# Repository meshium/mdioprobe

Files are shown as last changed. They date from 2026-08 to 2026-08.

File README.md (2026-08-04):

# mdioprobe v2

An MDIO probe on a custom STM32G474CET6 board: it watches a Clause-22 bus
without touching it, and it can drive one.

- **Passive capture.** The analogue MDIO and MDC lines go through comparators
  with a DAC threshold; TIM3 counts 32 MDC edges from the start bit, an HRTIM
  latch turns that into chip-select for SPI2 in slave mode, and the CPU only
  decodes finished frames. No per-frame software setup, so a busy bus does
  not outrun it — 284350 consecutive frames from an 88E6321 PPU at 6.25 MHz
  MDC with no decode errors, ring overruns or DMA faults.
- **Active master.** Bit-banged Clause 22 up to 2.5 MHz through a tri-state
  buffer powered from a programmable supply, so MDC comes out at the target's
  own logic level. Reads go back through the same comparator front end, which
  is why no receive-side translator is needed.
- **Level-agnostic.** The target's rail is measured, not assumed: 1.8, 2.5 and
  3.3 V buses are detected and every threshold derives from that one number.
  Until a rail is known, capture and the master both refuse to run.
- **Chip identification.** Registers 2 and 3 are looked up in a table
  extracted from the Linux kernel sources — 302 PHYs and 120 DSA switches,
  frozen into the firmware, so it works on a blank volume.

The command interface is a MicroPython CLI over USB CDC ACM, with history,
TAB completion, output redirection to files and a QSPI NOR volume for scripts
and logs.

```
mdio /flash> probe
phy 05: 4f51e91a  YT8531S Gigabit Ethernet
1 device(s) answered with an identifier

mdio /flash> read 5 2-3
reg 0x02 = 0x4f51
reg 0x03 = 0xe91a
```

## Building

Zephyr, with the board definition in-tree. The MicroPython submodule is
needed first:

```
git submodule update --init --recursive
./build.sh              # build
./build.sh flash        # build and flash over SWD
```

`build.sh` is the only supported entry point. It sources the Zephyr
environment, pins a toolchain and calls `west`, and it takes nothing on trust
from the machine it runs on:

| | |
| :-- | :-- |
| `ZEPHYR_BASE` | the Zephyr tree; defaults to `~/zephyrproject/zephyr` |
| `MDIOPROBE_SDK` | which SDK; defaults to the newest `~/zephyr-sdk-*` |
| `MDIOPROBE_VENV` | virtualenv to activate, and only when `west` is not already on `PATH` |

If your Zephyr environment is already active, the script uses it and changes
nothing. If a path is missing it says which one, rather than failing deep
inside CMake.

## Console

There is no VCP on the board. The log and the CLI share **USB CDC ACM**
(`/dev/tty.usbmodem*`); SWD on PA13/PA14/PB3 is for debugging. `tools/con.py`
is the bench driver for the console.

`help` lists the commands and `help <command>` explains one. USB is either the
console or a mass-storage device, never both at once: `msd` hands the volume
to the host and takes the console away until the probe is unplugged.

## Layout

```
src/            firmware; the public surface is include/mdioprobe_api.h alone
src/python/     the CLI, frozen into the image
boards/         the board definition (HWMv2)
hardware/       KiCad project: schematic, PCB, gerbers
docs/CAPTURE.md   how a frame is captured, end to end
docs/HARDWARE.md  pinout, connector, and what the schematic actually does
tools/con.py    console driver for the bench
tools/upload.py put files on the volume without unplugging
```

Zephyr APIs are used for ADC, GPIO, flash, UART, I2C and USB; the comparators,
TIM3, HRTIM, the SPI2 slave ring and the bit-bang master are driven through
STM32Cube LL and direct register writes, because Zephyr does not expose the
COMP-to-timer crossbars and its STM32 SPI slave driver races its own DMA.

## Status

Pre-release. Bring-up is complete and verified on hardware, including capture
against a real external master. Not yet exercised: the `uart` and `i2c`
connector personalities, and the short-circuit latch on the programmable
supply.

## Licence

Two objects, licensed separately, which is the usual practice for open
hardware and the only one that reads sensibly — a software licence does not
define what "object form" or "linking" mean for a printed circuit board.

- **Firmware and everything else: Apache-2.0**, text in `LICENSE`. The image
  is a static link, so a binary release carries Zephyr, MicroPython, the
  STM32Cube LL drivers, FatFs and picolibc with it; `NOTICE` lists each
  component and its terms and belongs with the binary, not only with the
  source.
- **The board, under `hardware/`: CERN-OHL-P-2.0**, text in
  `hardware/LICENSE`. Permissive, to match the firmware, and written for
  hardware — unlike a Creative Commons licence it grants patent rights, which
  for a circuit board is the part that matters.

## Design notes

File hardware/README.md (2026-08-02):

# mdioprobe v2 — board

SPDX-License-Identifier: CERN-OHL-P-2.0

KiCad 8 project for the probe: schematic, PCB, the footprints that are not in
the standard libraries, and a gerber set.

```
mdioprobe.kicad_sch     schematic
mdioprobe.kicad_pcb     board
mdioprobe.netlist       netlist
footprints.pretty/      footprints not in the KiCad libraries
gbr/                    gerbers and drill files
```

The KiCad footprint cache (`fp-info-cache`) and per-user project settings
(`*.kicad_prl`) are not tracked: KiCad rebuilds the first from the libraries
on demand, and the second is local to whoever opened the project.

## Licence

Everything in this directory is under the **CERN Open Hardware Licence
Version 2 — Permissive** (`LICENSE` here, SPDX `CERN-OHL-P-2.0`).

**The firmware is not.** The rest of the repository is Apache-2.0, with its
own `LICENSE` and `NOTICE` at the top level. Hardware and software are
different objects in law and are licensed separately, which is the usual
practice and the only one that makes sense: a software licence has nothing to
say about what "object form" or "linking" mean for a printed circuit board.

CERN-OHL-P rather than a Creative Commons licence, for two reasons. It is
written for hardware — it defines Source as the design files, Product as the
thing you build from them, and it covers making and having made, none of
which a licence written for creative works addresses. And it grants patent
rights (§6.1), which CC 4.0 explicitly does not (§2(b)(2): "Patent and
trademark rights are not licensed"). For hardware that gap is in exactly the
place the risk lives — the design files would be yours to copy while the
right to build the thing was not.

Permissive rather than the reciprocal variant (CERN-OHL-S): it matches the
firmware's Apache-2.0, and the point of publishing this board is that people
can use it, including inside something they do not open.

There is no warranty and no liability, per sections 5 and 8 of the licence.
This is a bench instrument, not a certified one.

## What it is

STM32G474CET6 in LQFP48. Comparators with a DAC threshold on the MDIO and MDC
inputs, a tri-state buffer on the MDC output powered from a programmable
soft-LDO so the probe drives at the target's own logic level, QSPI NOR for
storage, and USB.

`docs/HARDWARE.md` in the repository root is the pinout, the connector, and
the parts of the schematic worth knowing about before changing anything —
including what the next board revision needs.

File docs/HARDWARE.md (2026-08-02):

# MDIO Probe v2 — hardware map

MCU: **STM32G474CET6**, LQFP48, 512 KB flash / 128 KB RAM, 170 MHz.
No crystal: HSI16 → PLL (M=4, N=85, R=2) = 170 MHz; USB FS on HSI48 + CRS.

**The missing crystal is not only a USB concern.** HSI16 is the only
reference behind anything that measures time. Measured on this unit:
`kernel uptime` against the host clock over 120 s runs **+660 ppm** fast,
and the MDC frequency measurement reads low by the same amount (−721 ppm
against a scope-confirmed 6.250 MHz). The datasheet allows ±1%. Framing
does not care — TIM3 counts real edges — but no absolute time figure from
this board is good beyond about three significant digits.

## 1. Full pin map

| Pin | Signal | Function in firmware |
| :-- | :-- | :-- |
| PA0 | SPI2_SCK source | COMP1_OUT (AF8), MDC digital → **PCB trace to PB13** |
| PA1 | MDC sense | COMP1_INP (Analog) — sniffed clock |
| PA2 | QSPI_NSS | QUADSPI1_BK1_NCS |
| PA3 | QSPI_SCK | QUADSPI1_CLK |
| PA4 | VREG_CTL | DAC1_OUT1 (buffered) → P-MOSFET gate |
| PA5 | — | unused |
| PA6 | QSPI_D3 | QUADSPI1_BK1_IO3 |
| PA7 | QSPI_D2 | QUADSPI1_BK1_IO2 |
| PA8 | SPI2_MOSI source | COMP7_OUT (AF8), MDIO digital → **PCB trace to PB15** |
| PA9 | LED_G | GPIO, active low |
| PA10 | SPI2_NSS source | HRTIM1_CHB1 (AF13), NSS latch → **PCB trace to PB12** |
| PA11 / PA12 | USB_N / USB_P | USB FS device (CDC ACM console) |
| PA13 / PA14 | JTMS / JTCK | SWD |
| PA15 | JTDI | reserved |
| PB0 | QSPI_D1 | QUADSPI1_BK1_IO1 |
| PB1 | QSPI_D0 | QUADSPI1_BK1_IO0 |
| PB2 | VREG | ADC2_IN12 — regulated translator supply sense |
| PB3 | JTDO | reserved |
| PB4 | — | unused |
| PB5 | PHY_RST | GPIO open-drain, no pull, active low |
| PB6 | MDC_EN | GPIO **open-drain**, active low — buffer enable; 4.7 kΩ pull-up to VREG |
| PB7 | MDC_OUT | GPIO push-pull — bitbang MDC into the buffer |
| PB8 | MDIO out / USART3_RX / I2C1_SCL | direct to connector; OD no pull (MDIO TX) / Analog (RX, or parked) |
| PB9 | USART3_TX / I2C1_SDA | direct to connector, 3.3 V; parked (Analog) in MDIO mode |
| PB10 | — | unused |
| PB11 | LED_R | GPIO, active low |
| PB12 | SPI2_NSS | AF5 — chip select from PA10 |
| PB13 | SPI2_SCK | AF5 — clock capture from PA0 |
| PB14 | MDIO sense | ADC1_IN5 + COMP7_INP (Analog) — sniffed bus **and** master read-back |
| PB15 | SPI2_MOSI | AF5 — data capture from PA8 |

Internal-only, no pins: **DAC3_CH1** → COMP1_INM (MDC threshold),
**DAC4_CH1** → COMP7_INM (MDIO threshold).

## 2. Target connector

| Line | Driven by | Notes |
| :-- | :-- | :-- |
| MDC (MDIO mode) | PB7 → SN74LV1T125DBV buffer | enabled by MDC_EN (PB6, active low, open-drain); buffer VCC = VREG, so MDC swings at the target's level — measured 1800 → 1816…1840 mV, 2500 → 2543…2566, 3300 → 3176…3200; output also loops back to PA1/COMP1 |
| USART3_TX / I2C1_SDA | PB9, **direct** | bypasses the buffer — fixed 3.3 V |
| MDIO | PB8 out + PB14 in | **two MCU pins, one connector line**: PB8 drives (OD), PB14 senses via COMP7 |
| USART3_RX / I2C1_SCL | PB8, direct | same pin as the MDIO driver, different personality |
| PHY_RST | PB5 | open-drain, no pull — pull-up must come from the target |
| GND | — | |

Exactly one personality is live at a time, and the two never overlap on the
shared connector line:

- **MDIO mode** — PB7 clocks the buffer, PB8 drives data, PB14 reads it back.
  PB9 is parked (Analog) and both serial peripherals sit in their "sleep"
  pinctrl state, so nothing loads the bus the analog front end measures. The
  MDIO drive pin is Analog while receiving, open-drain (no pull) while
  transmitting.
- **UART / I2C mode** — the buffer is **off** (otherwise it would fight PB9
  on the same connector line), PB8/PB9 drive the connector directly at a
  fixed 3.3 V. No level translation on this hardware revision: the
  programmable supply feeds only the MDC buffer. I2C is master-only, and SDA
  stays bidirectional end to end because it never crosses the buffer.

## 3. Programmable translator supply (vreg)

An external P-MOSFET pass element driven by DAC1_CH1 (PA4), Vout sensed by
ADC2_IN12 (PB2), a 20 kHz TIM6 ISR running the PI loop, and an ADC analog
watchdog for short-circuit cutoff.

The control tick is a **zero-latency IRQ**. It has to be: the bitbang
master holds `irq_lock()` for a whole frame, and an ordinary interrupt would
leave the loop blind for all of it. Measured on a back-to-back burst when a
frame was ~430 µs — 8-9 missed ticks — that cost 2711 mV of swing on an
1800 mV target, against 43 mV with the tick unmaskable.

Raising MDC to 1500 kHz shortened the frame to ~44 µs, so the exposure is now
under one tick and the burst test would no longer show the difference. The
zero-latency tick stays: `clock` can be wound back down to 10 kHz, where a
frame is 6.4 ms and the old numbers apply with interest.

**The board is missing a bleeder resistor from VREG to GND** (~1 kΩ). The
pass element can only source current, so without a discharge path an
overshoot decays through ~40 µA of leakage, which shows up as a sawtooth.
It is currently clipped on at the bench — put it on the next revision.

```
      Vin 3.3V
        ├───[ R_pu 100k-1M ]───┐
    ┌───┴────┐ S               │
    │P-MOSFET│ G ◄─────────────┴──── PA4  (DAC1_OUT1, buffered)
    └───┬────┘
        │ D ──► Vout (1.8-3.3 V) ──► MDC buffer / level translator supply
      [ Cout ]  └───────────────────  PB2  (ADC2_IN12)
        │
       GND
```

**Range: 1800–3000 mV regulated, above that pass-through.** This is a
property of the topology, not a setting: a series pass element needs some
voltage across it to be controllable, and Vin is only 3.3 V. At a 3000 mV
target the gate still moves the output by 20 mV per DAC code; at 3300 it
bottoms out at `dac_code = 0` and there is no regulation left.

So a request above 3000 mV puts the node into `PASSTHRU`: gate fully on,
output = the board's 3.3 V minus a fraction of a millivolt across Rds(on) at
our few milliamps. For a target with 3.3 V logic that is exactly right, and
tighter than the loop could manage anyway — 8 mV p-p under continuous
generation, against 63 mV at a regulated 3000.

Two things about `PASSTHRU` worth remembering:

- **Measuring the output stops meaning anything.** VDDA = VREF+ = the same
  3.3 V as Vin, so the ADC measures the rail against itself and always reads
  near full scale. Do not take an absolute value from it.
- **Short-circuit protection still works but loses discrimination.** The
  FAULT condition is "gate saturated AND the analog watchdog active for 100
  ticks". Gate saturation used to mean the loop had given everything it had;
  here it is true by construction, so only the 5 ms debounce remains. The
  threshold itself stays meaningful — a short pulls Vout down relative to
  VDDA.

There is nothing between 3000 and 3300: a request for 3100 would silently
deliver 3.29 V, so it collapses into pass-through and the driver says so.

Control interface: `mdioprobe_vreg_set()` / `_off()` / `_get()` in
`include/mdioprobe_api.h`; the PI gains and the short-circuit margin are
tunable through the private `src/mdioprobe_vreg.h`.

## 4. QSPI NOR

Winbond **W25Q80DVSNIG**, 8 Mbit, bank 1, memory-mapped window at 0x90000000.
Driven by Zephyr's `st,stm32-qspi-nor` driver; partitions `capture` (768 KB)
and `qspi-storage` (256 KB).

The `quadspi` DT node itself comes from Zephyr's G4 SoC dtsi — only pinctrl,
the flash child and partitions live in the board DTS.

**`writeoc = "PP_1_1_4"` is mandatory in the DTS.** The driver's default page
program opcode is 0x38 (PP_1_4_4), which this part does not implement — and
it does not fail: the write is accepted, nothing is programmed, and the
error only surfaces as a verification mismatch later. SFDP carries no
quad-program information, so nothing detects this automatically.

## 5. Hardware facts worth restating (confirmed against the schematic)

1. **Serial personalities are 3.3 V only.** PB8/PB9 reach the connector
   directly; the tri-state buffer and the programmable supply are on the MDC
   path alone. Only an I2C **master** and a UART are supported on this
   revision.
2. **The buffer is exclusive to MDC.** In UART/I2C mode `mdioprobe_serial.c`
   de-asserts MDC_EN; in MDIO mode PB9 is parked. The two sources never
   drive the connector line at once.
3. **Generated MDC loops back to PA1/COMP1** from the buffer output, so the
   frequency measurement and the threshold autocal have a clock source even
   with no external master. That self-trigger only fires when the line is
   genuinely idle — driving MDC into a bus that already has a master is a
   collision, and it also corrupts the measurement, because our ~130 kHz
   bitbang becomes the majority of the sample and the real megahertz clock
   is rejected as outliers.
4. **VDDA = VREF+ = 3.3 V**, which is what the DAC threshold maths in
   `mdioprobe_adc_dac.c` assumes.
5. **LED colours are PA9 = green, PB11 = red** — the reverse of the initial
   pinout notes, confirmed by watching an LED-only image on real hardware.
6. **MDC_EN must be driven open-drain.** The line has a 4.7 kΩ pull-up to
   VREG — the buffer's own supply. Push-pull HIGH feeds the 3.3 V domain
   into the VREG rail through that resistor; since the rail's only load is
   the buffer's quiescent current, it floats up to ~3.26 V regardless of
   the pass MOSFET, and the vreg loop saturates its gate fully shut trying
   to correct an output it does not actually control. Observed as
   `target=2989 measured=3257 dac_code=4095`.
7. **The MDC_EN release edge is measured and clean.** On a scope, OE rises
   **1…2.5 µs after the falling edge of the last MDC pulse**, with a steep
   edge — the 4.7 kΩ pull-up does not smear it, so the OE node capacitance
   is what the estimate assumed (τ ≈ 4.7 kΩ × 10-15 pF ≈ 50-70 ns). The
   1…2.5 µs is firmware, not RC: `irq_unlock()` sits between the last
   `mdc_set(0)` and the buffer being released, and the lock had been held
   for the whole frame, so every deferred interrupt flushes there. Harmless
   — MDC is parked low before the unlock and the bus rests low anyway.
   Releasing the buffer is deliberately kept **outside** the lock, so the
   load step does not land on a blinded vreg loop.
8. **The MDC buffer is a TI SN74LV1T125DBV** — a single-bit 3-state buffer
   and one-way level translator, VCC = VREG. Datasheet facts that matter:
   - **VCC range 1.8–5.5 V**, so VREG's whole 1.8–3.3 V span is in spec;
   - **inputs tolerate 5 V regardless of VCC** — driving PB7 push-pull at
     3.3 V into a buffer powered from 1.8 V is a designed-for case, not an
     overvoltage. No clamp-diode current, nothing to fix;
   - **OE is active low**, matching MDC_EN;
   - *reduced* input thresholds (at VCC 3.3 V it is specced for 1.8 V
     inputs, at 1.8 V for 1.2 V ones), so our 3.3 V swing is read reliably.

   Net effect: the input side lives in the MCU's 3.3 V domain, the output
   side swings at the target's level. Being a single buffer, it also
   confirms that only MDC crosses it — PB8/PB9 reach the connector direct.

9. **PB8 is also BOOT0 — every board needs `nSWBOOT0 = 0`.** RM0440 §2.6.1,
   Table 5: out of the factory `nSWBOOT0 = 1` (BOOT0 comes from the PB8 pin)
   and `nBOOT1 = 1`, so a high level on PB8 at reset release boots System
   memory — the ROM bootloader — instead of our firmware. PB8 carries MDIO
   straight to the connector, and any live target pulls that line up, so a
   factory-configured board **does not start at all once the target is
   connected**.

   One-time per board, over SWD:

   ```
   STM32_Programmer_CLI -c port=SWD mode=UR -ob nSWBOOT0=0
   ```

   BOOT0 then comes from the `nBOOT0` option bit, which is already 1 → main
   flash regardless of the pin. `west flash` does not set this — it is a
   per-device setting, not part of the image. A pull-down on PB8 is **not**
   an alternative: it would divide against the target's MDIO pull-up.

10. **MDIO needs a pull-up, and this board does not always have one.** The
    line is open-drain in both directions: PB8 only ever pulls low, so every
    '1' — including every bit the target sends back — is a resistor charging
    the line. Nothing on the MDC path helps here; the buffer is one-way and
    on the other wire entirely.

    Two v2 boards exist, one with an external pull-up fitted on MDIO and one
    without, and the difference is not cosmetic: on the board without it a
    Marvell 88E6321 returned nothing but `0xffff` to every read, while the
    same firmware on the pulled-up board read it correctly. The switch's own
    internal weak pull-ups are **not** sufficient. Note that this contradicts
    the assumption in item 9 that "any live target pulls that line up" — a
    target may well not, which is also why that board still booted.

    The failure looks exactly like clocking MDC too fast, and it is worth
    knowing that it is not: an all-`0xffff` read is a floating line far more
    often than it is a slow one, and slowing `clock` will not rescue it.
    Fit the pull-up. Every board should carry one — 1.5–4.7 kΩ to the
    target's rail (i.e. to VREG, not to 3.3 V) — and that belongs in the
    next revision alongside the vreg bleeder.

    Decided for that revision: **one resistor behind a switch**, not a
    permanent one. Permanent to VREG would break the rail measurement in
    both directions — with VREG off the resistor is a path to a dead node,
    with VREG on the probe would be measuring its own rail and could never
    see the target leave. The switch stays open until the rail is known,
    which keeps today's automatic detection exactly as it is and adds the
    case it cannot handle.

    What the firmware owes in return: while the switch is closed the probe
    can no longer tell the rail or whether a target is attached — no passive
    observer can distinguish 1.8 V from 3.3 V on a wire it is holding up
    itself — so that state has to be visible in `diag` and on the LED rather
    than discovered.

11. **How fast MDC can actually go, measured three ways.** These are three
    different limits and only the first belongs to the probe:

    | Limit | Rate | What sets it |
    | :-- | :-- | :-- |
    | Bit loop | ~4.0 MHz | GPIO writes, the shift-and-mask and the cycle-counter spin, at 170 MHz and `-Os` |
    | Clause 22 | 2.5 MHz | IEEE 802.3 §22.2.2.11, the specified MDC maximum |
    | This bench | ~1.8 MHz | an 88E6321 over a short lead stops answering above it |

    The bench figure is a sweep, not an estimate: 1205, 1317, 1556 and
    1762 kHz delivered gave 10/10 correct switch-ID reads each, while
    2096 kHz and above gave 0/10. Nothing in between was tried, so the edge
    is somewhere in that gap. The firmware default is 1500 kHz, which leaves
    margin under it; 300 indirect reads at 1451 kHz delivered ran with no
    mismatches and no errors.

    Since MDIO is open-drain, the third row is a property of the pull-up and
    the wiring rather than of either device, so expect it to move with the
    lead and the resistor. A stronger pull-up is the thing to try if a target
    needs to run faster.

12. **The MDC buffer stays enabled between frames, and MDC is driven while
    it does.** The firmware releases it 20 ms after the last frame rather
    than after each one, so a series of transactions enables it once. While
    it is up, PB7 drives MDC through the buffer and holds it low at idle —
    which means that for those 20 ms the probe owns the clock line and
    another master on the same wire cannot use it.

    Observable without a scope: with the buffer released, the target's
    pull-up wins and `diag` reports `comp MDC: 200/200 high`; immediately
    after a frame it reads lower, because part of the sampling window caught
    the line held low.

    What this buys is the settle. Enabling the buffer is a load step on the
    VREG rail, so it is followed by a 1 ms wait whenever the supply is
    regulating — paying that once per series instead of once per transaction
    is the whole point. In pass-through there is no loop to protect and the
    wait is skipped entirely (measured: a 200-transaction burst leaves the
    rail inside its idle window either way, and the transaction drops from
    1081 µs to 84).

13. **The bench target's "PPU traffic" is the switch polling two external
    PHYs, and one scratch bit decides whether that bus exists.** This was
    used blind through the whole bring-up — `mv scratch modify clear 6 0x63
    0x80` made frames appear and setting the bit again silenced them — so
    the mechanism is worth writing down.

    On the 88E6321, `scratch[0x63]` bit 7 is `NormalSMI` (Functional
    Specification Table 208, p. 334). With P5_MODE not 0x1 or 0x2, the
    P5_COL and P5_CRS pins become MDIO_PHY and MDC_PHY *if the NO_CPU strap
    was one at reset*; clearing the bit inverts the sense of that strap.
    Nothing else routes an external MDIO bus off this part.

    On this bench NO_CPU is 0 (`scratch[0x71] = 0x83`), so the pins carry
    the external bus only with NormalSMI **cleared**. Measured both ways:
    with it set, PHY addresses 5 and 6 read `0xffff`; with it cleared they
    answer (BMSR 0x7949, ID 0x4f51/0xe91a). External PHYs sit on ports 5
    and 6 of this board, so those are the two the PPU polls, and that is
    the traffic the capture chain was verified against.

    Address map, since the same window reaches all of them (spec §9.3):
    internal PHYs of ports 3 and 4 at SMI addresses 3 and 4, internal
    SERDES of ports 0 and 1 at 0x0C and 0x0D, external PHYs at the address
    matching their port number. `mv extbus` and `mv id` print all of this.

    **Two ways to an external PHY, and they are independent.** The SMI PHY
    window reads the PHY's registers directly. The PPU is the other one: it
    polls the PHY whose SMI address matches the port number and publishes
    link/speed/duplex into that port's status register for the MAC. Only
    the second needs the port's `PHYDetect` bit (Port offset 0x00 bit 12),
    and **the PPU's own detection does not always set it** — measured here,
    ports 5 and 6 stayed `no PHY detected` with the bus routed and both
    PHYs answering, through a soft reset as well.

    PHYDetect is the one writable bit in that register and the spec says
    the poll routine follows it, so setting it by hand is the fix
    (`mv port <sw> <ports> detect on`). Measured: port 5 went from
    `0x0e07` — link up, 1000 Mbps, no PHY detected — to `0x1007`, link
    down with the PHY detected, i.e. the PPU replaced a status that had
    not come from a PHY at all with the real one. A Global1 software reset
    re-runs PPU init and rewrites the register, so the setting does not
    survive one.

    One more thing that only the spec says: the switch's SMI PHY window
    (Global2 0x18/0x19) works **only while the PPU is enabled** — with it
    off, SMIBusy self-clears and every read returns `0xffff`. The enable is
    Global1 0x04 bit 14, which the register table calls "Reserved, must be
    set to 1" while the footnote under the SMI PHY register names it. Note
    it is *not* PPUState in Global1 0x00 bit 15: measured with the PPU
    disabled, status went 0xc800 → 0x8800, so bit 15 stayed at "polling".

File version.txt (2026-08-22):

# Release version of the firmware.
#
# MAJOR and MINOR are bumped deliberately, by hand — they say what release
# this is meant to be. PATCH is counted rather than chosen: a commit hook
# increments it and stages the result, so every commit carries its own. The
# build itself never writes here.
MAJOR=0
MINOR=1
PATCH=14

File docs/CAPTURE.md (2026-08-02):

# MDIO Capture — End-to-End Flow

This document describes the complete data path for capturing a single
Clause-22 MDIO frame: from the analog wire on the target board, through
the on-chip analog/timer/SPI front end, to a 32-bit decoded frame in
RAM. It is the reference for understanding *why* every peripheral is
configured the way it is in `src/mdioprobe_*.c`.

---

## 1. Why hardware-only capture

Clause-22 MDIO at 2.5 MHz means an MDC edge every 200 ns; live PPU
traffic from the MV88E6321 runs faster still (~6.27 MHz). A
software-ISR-per-bit approach is out of the question on a 170 MHz
Cortex-M4. Even DMA-from-GPIO is awkward because the start of a frame
is not self-clocked — we have to detect the preamble→ST=0 transition to
lock onto the 32-bit data field.

We solve this by chaining on-chip peripherals so the CPU is involved
only in **decoding the captured 32-bit word**, never in clocking,
edge-detection, or framing:

```
analog → comparators → TIM3 counter + HRTIM latch (NSS) → SPI2 slave + DMA → RAM
```

The CPU sleeps in `k_sleep(2 ms)` polling a ring-buffer index while the
hardware does the rest.

---

## 2. Structural block diagram

```
   ┌─────────────────────────── mdioprobe_v2 board ────────────────────────────┐
   │                                                                           │
   │  Target ── MDC ──► PA1 ──►┌ COMP1 ┐                                       │
   │                           │ + -   │ comp1_out ─► PA0 (AF8) ─[trace]► PB13 │
   │            DAC3_CH1 ─────►┘       │            (digital MDC)    SPI2 SCK  │
   │            (MDC threshold, internal-only)                                 │
   │                                                                           │
   │  Target ── MDIO ─► PB14 ──►┌ COMP7 ┐                                      │
   │            (ADC1_IN5)      │ + -   │ comp7_out ─► PA8 (AF8) ─[trace]► PB15│
   │            DAC4_CH1 ──────►┘       │            (digital MDIO)  SPI2 MOSI │
   │            (MDIO threshold, internal-only)                                │
   │                                                                           │
   │  comp1_out ─internal─► TIM3_ETR  (external clock, MDC edges)              │
   │  comp7_out ─internal─► TIM3_TI1  (trigger)  and  HRTIM EEV5               │
   │                                                                           │
   │  ┌──────────── TIM3 (one-pulse, ARR=32) ─────────────┐                    │
   │  │  trigger (comp7_out ↓ = ST) starts the counter    │                    │
   │  │  ETR (comp1_out ↑ = MDC) clocks it 0→32           │                    │
   │  │  OPM stops at 32; MMS=Enable → TRGO = CNT_EN      │                    │
   │  └──────────────────────┬────────────────────────────┘                    │
   │                         │ tim3_trgo (CNT_EN) ─internal─► HRTIM EEV3       │
   │  ┌──────────── HRTIM1 Timer B — NSS SR latch ────────┐                    │
   │  │  SETx1R = EXTEVNT5 (comp7_out ↓)  → NSS LOW       │                    │
   │  │  RSTx1R = EXTEVNT3 (CNT_EN ↓ @32) → NSS HIGH      │                    │
   │  │  OUTxR.POL1 = 1  → output active-low              │                    │
   │  └──────────────────────┬────────────────────────────┘                    │
   │                         ▼                                                 │
   │              CHB1 = PA10 (AF13) ─[trace]──► PB12 (SPI2 NSS)               │
   │                                                                           │
   │  ┌──────── SPI2 slave (custom LL driver) ────────┐                        │
   │  │  CPHA=0 CPOL=0, MSB-first, 8-bit, NSS hard in │                        │
   │  │  RXDMAEN=1, FRXTH=QUARTER (RXNE per byte)     │                        │
   │  └────────────┬──────────────────────────────────┘                        │
   │               │ RXNE → DMA request 12 (SPI2_RX)                           │
   │  ┌──── DMAMUX1 ch0 → DMA1 Channel 1 ────┐                                 │
   │  │  P→M, byte, MINC, CIRCULAR, 256 B    │                                 │
   │  │  TE IRQ only; position = CNDTR       │                                 │
   │  └────────────┬─────────────────────────┘                                 │
   │               ▼                                                           │
   │   uint8_t mdio_rx_buf[64 × 4]  ← 64-slot ring of 32-bit frames            │
   └───────────────────────────────────────────────────────────────────────────┘
```

---

## 3. Signal chain, step by step

### 3.1 Analog input
- **MDC** on PA1 (COMP1 positive input).
- **MDIO** on PB14 (COMP7 positive input — also ADC1_IN5 for idle
  voltage sense; analog mode lets both peripherals read the pin
  without a pinmux conflict).
- Both pins set to `LL_GPIO_MODE_ANALOG`, no pull (target board
  provides the MDIO pull-up).

### 3.2 Threshold generation
The comparator negative inputs are driven by internal DACs:
- **DAC3_CH1 → COMP1_INM** (MDC threshold, INMSEL=100).
- **DAC4_CH1 → COMP7_INM** (MDIO threshold, INMSEL=100).

**Why DAC3 / DAC4?** Both are silicon **internal-only** on STM32G4 —
no bond wire to a package pin. The high-impedance reference node is
purely on-die, so there is nothing for neighbouring AF switching to
capacitively couple into. DAC1/DAC2 have external pins that would act
as antennas and corrupt captures with 0xff/0x00 garbage bytes
(confirmed empirically on this hardware). The Zephyr DAC driver
mandates pinctrl, which DAC3/DAC4 cannot provide, so they are
configured directly via LL (`CONFIG_DAC` is off).

Thresholds are derived from the **bus rail** at 30%. The rail comes
from the target detector (`mdioprobe_bus.c`), which measures the MDIO
idle level on PB14 with ADC1 and classifies it into 1.8 / 2.5 / 3.3 V;
the API applies the threshold when a function that needs the
comparators starts, so a caller never sets it by hand.

The measurement is the **peak of a 64-sample burst**, not a single
reading: MDIO is open-drain pulled up to the rail, so the high level is
the one that means something, and one sample lands wherever traffic
happens to be. Measured against live PPU traffic, the single-sample
version reported 2549, 2856, 2923, 3167 and 3299 mV on successive boots
for the same 3.3 V rail — and both the threshold and the translator
supply were set from it.

`mdioprobe_dac_set_threshold()` and `mdioprobe_dac_set_mdio_threshold()`
still override manually for bench work — useful for dropping the MDIO
threshold alone so the open-drain rising edge is caught early at high
MDC, while MDC (push-pull) keeps the symmetric threshold.

### 3.3 Digital conversion (comparators)
- **COMP1** (MDC): `+`=PA1, `-`=DAC3_CH1, non-inverted, no hysteresis,
  no output blanking. Output appears on **PA0** (AF8).
- **COMP7** (MDIO): `+`=PB14, `-`=DAC4_CH1, same options. Output
  appears on **PA8** (AF8).
- Each comparator output is also routed *internally* (no pin needed)
  to the timer fabric as `comp1_out` / `comp7_out`.

PCB traces carry the digital outputs into SPI2:
- **PA0 → PB13** (SPI2 SCK).
- **PA8 → PB15** (SPI2 MOSI).

### 3.4 Frame delimiting (TIM3 counter + HRTIM latch)

NSS — the SPI2 chip-select that gates exactly one 32-bit frame — must
be **HIGH when idle** and pulse **LOW for exactly the 32 data bits**,
starting at the frame's ST=0 edge with zero delay.

A plain general-purpose timer cannot produce this. A GP-timer output
compare is a level comparison against the counter value, and an
OPM-parked counter sits at the same value (0) that the pulse starts
from — so "HIGH idle + zero-delay LOW pulse" is unreachable with one
OC channel. The HRTIM output, by contrast, is a true **SR latch**:
independent set and reset event sources, and it *holds* its level
between events. The design therefore splits the job:

**TIM3 — the MDC edge counter** (`mdioprobe_tim3_count_init`):
- `TI1` ← `comp7_out`, falling edge — the preamble→ST=0 transition is
  the trigger.
- `ETR` ← `comp1_out`, rising edge, external clock mode 2 — the
  counter is clocked by real MDC edges.
- Slave mode = **trigger**: each trigger starts the counter (it is not
  reset). Combined with **one-pulse mode**, mid-frame MDIO 1→0
  transitions, which arrive while the counter runs, are ignored.
- `ARR = 32`: the update event (UEV), where OPM clears the counter
  enable, lands exactly 32 MDC edges after the trigger.
- `MMS = Enable`: TRGO carries the **CNT_EN** signal — HIGH while the
  counter runs, LOW when it stops. Its *falling* edge is the OPM stop
  at the 32nd MDC tick.

Because the counter counts real edges, there is no fMDC calibration,
no blanking window, and the inter-frame gap is irrelevant — the
counter is simply stopped between frames.

**HRTIM1 Timer B — the NSS SR latch** (`mdioprobe_hrtim_nss_init`):
- `EEV5` ← `comp7_out`, falling edge (RM0440 Table 240, EE5SRC=10).
- `EEV3` ← `tim3_trgo`, falling edge (EE3SRC=10) — catches CNT_EN ↓.
- `OUTxR.POL1 = 1` → the CHB1 output is **active-low**: inactive
  (idle / post-reset) level is HIGH, active level is LOW.
- `SETx1R = EXTEVNT5`: MDIO ↓ at ST sets the latch → **NSS LOW**.
- `RSTx1R = EXTEVNT3`: CNT_EN ↓ at the 32nd MDC tick resets it →
  **NSS HIGH**.
- At init, an `SRT` (software reset) write prepositions the latch
  inactive = HIGH before the output is connected to the pin.

Mid-frame MDIO ↓ edges re-fire `EXTEVNT5` while NSS is already LOW —
a harmless no-op on a set latch. During the preamble there are no MDIO
falling edges, so NSS stays HIGH until the next ST.

**Set/reset priority** (RM0440 §28.3.7): if `EXTEVNT5` (set) and
`EXTEVNT3` (reset) fall within the same tHRTIM period — possible right
at the 32-MDC boundary — **reset wins and set is ignored**, so the
boundary always resolves cleanly to NSS HIGH.

Result: CHB1 (PA10) stays HIGH at rest and pulses LOW for exactly the
32 MDC of one data field. PA10 is traced to **PB12**, SPI2's hardware
NSS input.

### 3.5 SPI slave capture
SPI2 is configured by the **custom LL driver** in
`src/mdioprobe_mdio_api.c`. Key settings:
- `LL_SPI_MODE_SLAVE`.
- `LL_SPI_PHASE_1EDGE` (CPHA=0): MOSI sampled on the **rising** SCK
  edge.
- `LL_SPI_POLARITY_LOW` (CPOL=0): SCK idle is LOW.
- `LL_SPI_DATAWIDTH_8BIT`, MSB first — four 8-bit transfers = 32-bit
  frame.
- `LL_SPI_NSS_HARD_INPUT` — SPI shifts only while NSS (PB12) is LOW.
- `LL_SPI_RX_FIFO_TH_QUARTER` — RXNE fires per byte.
- `EnableDMAReq_RX(SPI2)` — each RXNE raises a DMA request.
- Full-duplex direction (default); the TX/MISO side is unused.

CPOL=0 / CPHA=0 matches what the comparators produce: MDIO is valid
on the rising edge of MDC (Clause 22), so SPI samples MOSI = MDIO on
every MDC rising edge — exactly the intent.

### 3.6 DMA transfer
- **DMA1 Channel 1** (DMAMUX channel 0 → DMA1_Ch1 is the simplest
  fixed mapping).
- **DMAMUX1 channel 0** routed to request **12** (`SPI2_RX`).
- Direction peripheral→memory, byte size, peripheral fixed, memory
  increment, **CIRCULAR** mode, priority VERYHIGH.
- Source `&SPI2->DR`; destination `mdio_rx_buf` (64 slots × 4 bytes =
  256 B). Each NSS-LOW window deposits one 4-byte frame; after 64
  slots the DMA wraps and overwrites the oldest.
- Only the `TE` (transfer-error) interrupt is enabled on
  `DMA1_Channel1_IRQn`, and it only counts errors. There is no write
  cursor to advance: the consumer derives the write position from CNDTR
  byte-exactly, which is what lets a lone frame surface instead of
  waiting for a half ring to fill.

### 3.7 Decode
`mdio_decode_frame()` interprets the 32-bit big-endian word
according to the Clause-22 format:

| bits  | field | meaning |
| ----- | ----- | --- |
| 31:30 | ST | Start of Frame (always `01`) |
| 29:28 | OP | Opcode: `01` write, `10` read |
| 27:23 | PHY | PHY address (5 bits) |
| 22:18 | REG | Register address (5 bits) |
| 17:16 | TA | Turn-around (driver-dependent, ignored) |
| 15:0  | DATA  | 16-bit register data |

The DMA write pointer's byte offset (0..3) at boot is stochastic, so
the first `sniff_one` scans all four cyclic rotations for the one that
yields `ST=01` AND `OP ∈ {01,10}`, locks it, and applies it to every
later decode. `ST != 01` after lock flags `out->err = -1` (torn
frame).

---

## 4. Software flow

### 4.1 Boot-time init

Owned by `mdioprobe_init()` in `src/mdioprobe_api.c`, which is where the
ordering constraints below are enforced rather than left to a caller.

1. `mdioprobe_adc_dac_init()` — ADC1 ready, DAC3_CH1 / DAC4_CH1
   configured via LL for internal-only output.
2. Thresholds come from the **bus rail**, not from a raw reading: the
   detector (`mdioprobe_bus.c`) classifies the MDIO idle level into
   1.8 / 2.5 / 3.3 V and the API applies `rail × 0.30` when a function
   that needs the comparators starts. The level itself is the peak of a
   64-sample burst — a single sample lands wherever traffic happens to
   be, and on a live bus that read anywhere from 2549 to 3299 mV for the
   same 3.3 V rail.
3. `mdioprobe_tim3_count_init()` — TIM3 as the MDC edge counter
   (TI1←comp7_out, ETR←comp1_out, slave-trigger, OPM, ARR=32,
   MMS=Enable). Runs before COMP so the TI1/ETR muxes are locked
   before the comparators toggle.
4. `mdioprobe_hrtim_nss_init()` — HRTIM1 Timer B NSS latch
   (EEV5←comp7_out, EEV3←tim3_trgo, SET/RST crossbar, CHB1→PA10/AF13).
   Runs after TIM3 — it consumes TIM3's TRGO.
5. `mdioprobe_comp_init()` — PA1/PB14 → analog; PA0/PA8 → AF8;
   COMP1 / COMP7 configured and enabled.
6. `mdioprobe_mdio_init()` — DMA1/DMAMUX1/SPI2 clocks; SPI2 (slave,
   mode-0, 8-bit MSB, hardware NSS, RX DMA); DMAMUX ch0 → request 12;
   **DMA1_Channel1 in CIRCULAR mode** over the 64-slot ring; only the
   **TE** (transfer-error) IRQ is connected. SPI and DMA are enabled and
   **left running indefinitely** — steady-state capture is touch-free.
   HT/TC used to be enabled to advance a write cursor; that cursor is
   gone (see 4.2) and they served nothing else.
7. `mdioprobe_serial_init()` and `mdioprobe_vreg_init()` — connector
   personality and the translator supply.
8. `mdioprobe_bus_start()` — the target detector thread. It drives the
   base layer of the indication and gates capture and the master: until
   the rail is known, both refuse to run.

### 4.2 Steady-state continuous capture

After boot there is **no per-frame software reconfiguration**. SPI
and DMA run continuously; frames land in the ring as they arrive.

```
┌─ Frame gating hardware (per frame, no CPU) ──────────────────────┐
│                                                                  │
│ MDIO falling edge (preamble→ST=0)                                │
│   ├─► HRTIM EEV5 ─► SETx1R ─► CHB1 LOW  (= NSS asserted)         │
│   └─► TIM3 TI1 trigger ─► one-pulse counter starts               │
│                                                                  │
│ 32 MDC rising edges clock TIM3 (ETR)                             │
│   └─► UEV: OPM stops the counter, CNT_EN falls                   │
│        └─► HRTIM EEV3 ─► RSTx1R ─► CHB1 HIGH (= NSS deasserted)  │
│                                                                  │
│ Preamble of next frame: no MDIO ↓ → NSS stays HIGH               │
└──────────────────────────────────────────────────────────────────┘

┌─ SPI2 + DMA1 (per frame, no CPU) ────────────────────────────────┐
│ NSS LOW (from CHB1 trace) enables the SPI slave                  │
│ 32 SCK rising edges (from comp1_out trace):                      │
│   each samples MOSI=MDIO → 8-bit shift; every 8 bits RXNE→DMA    │
│ DMA copies 4 bytes SPI->DR → mdio_rx_buf[next slot]              │
│ No interrupt. The write position is CNDTR, read on demand.       │
└──────────────────────────────────────────────────────────────────┘

┌─ mdioprobe_mdio_sniff_one_to (consumer) ─────────────────────────┐
│ head = (BUF - CNDTR) & (BUF-1)          ← byte-exact, no cursor  │
│ written = (head - slot_base) mod BUF                             │
│ frame k is ready once written >= off + 4  (BYTES, not slots)     │
│ if written > BUF - 8: overrun++, resync to the live edge         │
│ snapshot mdio_rx_buf[read_slot], read_slot = (read_slot+1) % 64  │
│ decode → return frame                                            │
└──────────────────────────────────────────────────────────────────┘
```

The write cursor used to be a variable advanced by the DMA half/full
transfer interrupts — **once per half ring, i.e. every 32 frames**. A
frame therefore sat undelivered until 31 more arrived behind it, which
was invisible at PPU rates and fatal on a bus polled once a second.
Readiness is now derived from CNDTR in bytes, so a single frame surfaces
on its own.

### 4.3 Why the continuous-capture design

- **No per-frame SPI disable/re-enable.** Earlier designs
  reconfigured SPI between captures; the ~2-3 µs disabled window
  could swallow a frame's NSS edge and capture "tail of N + head of
  N+1". Continuous mode removes the window.
- **CIRCULAR DMA + ring buffer absorbs consumer jitter.** 64 slots ×
  4 bytes at PPU rates holds tens of ms of history, so the deferred
  Zephyr log thread can burst without dropping frames.
- **NSS HARD INPUT auto-aligns SPI between frames.** STM32 SPI slave
  resets its shift counter on every NSS-HIGH transition, so each
  NSS-LOW window starts clean — exactly 32 SCK → 4 bytes → one slot.
- **DMA byte alignment is auto-detected** — CIRCULAR DMA never resyncs
  to frame boundaries, so a constant 0..3-byte rotation is locked in
  software (`mdio_detect_offset` / `mdio_window_is_c22`). Two rules earn
  their keep. A candidate window must have ST=01, OP ∈ {01,10} **and**,
  for a write, TA=10 — the master drives that turnaround, so it is a
  hard check; without it a window straddling a frame boundary passes and
  the detector locked the wrong offset in 5 runs out of 8 on real PPU
  traffic. And when more than one candidate passes, the slot is dropped
  rather than guessed. The offset is a property of the **stream**, not
  the session: it shifts when the traffic changes, so starting a capture
  re-arms the detection.

---

## 5. Critical timing notes

| Concern | Mitigation |
| --- | --- |
| Comparator output glitches before threshold settles | Threshold written before COMP enable. The idle level behind it is the peak of a 64-sample burst, not one reading — one sample lands wherever traffic is and mis-sets both the threshold and the translator supply. |
| Comparator reference noise | Thresholds use DAC3/DAC4 — internal-only on G4, no package pins, so no antenna for switching noise. DAC1/DAC2 (bonded pins) corrupted captures and were abandoned. |
| Open-drain MDIO slow rising edge at high MDC | The MDIO threshold is settable independently of MDC's, so the rise can be caught early while MDC (push-pull) keeps the symmetric threshold. |
| Mid-frame MDIO 1→0 retriggering the frame | TIM3 one-pulse mode is single-shot per trigger; mid-frame edges arriving while the counter runs are ignored. No HRTIM blanking window needed. |
| NSS idle level | The HRTIM output is an SR latch (POL1=1) — it holds HIGH between frames. A GP-timer OC cannot do this (idle level is tied to the pulse-start level); hence the TIM3+HRTIM split. |
| set/reset coincidence at the 32-MDC boundary | RM0440 §28.3.7: reset has priority over set — the boundary resolves to NSS HIGH. |
| HRTIM output stuck after init | `SRT` preposition write forces NSS inactive HIGH before `TBCEN` → `OENR`. |
| SPI bit-offset drift between captures | CIRCULAR DMA + always-on SPI — no per-frame reconfig; NSS HARD INPUT realigns the SPI shift counter every NSS-HIGH. |
| Lost frame between sniffer iterations | 64-slot ring absorbs consumer (log thread) burstiness. |

---

## 6. Pin map summary

Capture-path pins only.

| Function | Pin | Mode | Notes |
| --- | --- | --- | --- |
| MDC sense | PA1 | Analog (COMP1+) | target MDC wire |
| MDIO sense | PB14 | Analog (COMP7+, ADC1_IN5) | target MDIO wire; also the master's read-back |
| MDC threshold | (DAC3_CH1) | internal | no GPIO (internal-only DAC) |
| MDIO threshold | (DAC4_CH1) | internal | no GPIO (internal-only DAC) |
| MDC digital out | PA0 | AF8 (COMP1_OUT) | **PCB trace** → PB13 |
| MDIO digital out | PA8 | AF8 (COMP7_OUT) | **PCB trace** → PB15 |
| NSS gen | PA10 | AF13 (HRTIM1_CHB1) | **PCB trace** → PB12 |
| SPI2 SCK | PB13 | AF5 | receives PA0 |
| SPI2 MOSI | PB15 | AF5 | receives PA8 |
| SPI2 NSS | PB12 | AF5 | receives PA10 |
| Target reset | PB5 | GPIO open-drain, active LOW | 10 ms pulse at boot; pull-up must come from the target |

TIM3 drives no GPIO — its TI1/ETR inputs and TRGO output are all
internal signals.

There is no CPU-side bitbang MDIO bus on this board: the probe's own
Clause-22 master uses PB6/PB7/PB8 through the level-translating buffer,
and the switch that generates test traffic is managed from a separate
probe.

---

## 7. Software / config dependencies

`prj.conf` deliberately keeps things minimal:
- `CONFIG_SPI=y` + `CONFIG_SPI_SLAVE=y` — only so the stm32 SPI
  driver applies pinctrl on the `&spi2` node at init. Its API is
  never called.
- No `CONFIG_DMA` — the custom LL driver owns DMA1_Channel1.
- `CONFIG_ADC=y` — Zephyr API for the ADC1 idle-voltage measurement.
- `CONFIG_DAC` is **off** — the threshold DACs are DAC3/DAC4
  channels, internal-only on G4 (no pins), so the pinctrl-mandating
  Zephyr DAC driver cannot manage them. They are configured via LL.
- **No `CONFIG_MDIO`.** There is no Zephyr MDIO bus on this board; the
  Clause-22 master is bitbanged directly in `mdioprobe_mdio_master.c`
  because `zephyr,mdio-gpio` assumes one bidirectional pin and this
  hardware drives and senses on two (PB8 out, PB14 in through COMP7).
- `CONFIG_ZERO_LATENCY_IRQS=y` — the vreg control tick must run through
  the master's `irq_lock()`, or the rail collapses during a frame.
- `CONFIG_SHELL=y` — interactive shell over USB CDC ACM, with enlarged
  RX ring and command buffers (long `flash` commands overran the 64-byte
  defaults and the shell silently executed the remainder).

HRTIM and TIM3 have no Kconfig — both are driven entirely via LL and
direct register writes.

Board definition lives in-tree at `boards/meshium/mdioprobe_v2/`, picked
up via `BOARD_ROOT` from `CMakeLists.txt`; there is no Nucleo overlay.
Relevant nodes:
- `mdioprobe_config` with `io-channels = <&adc1 5>` and
  `target-reset-gpios` on PB5.
- `mdio_master` — describes PB6/PB7/PB8 even though the code muxes them
  itself; `BUILD_ASSERT`s in `mdioprobe_mdio_master.c` break the build if
  DT and code disagree.
- `spi2` enabled but **without** `dmas` — the node exists only so its
  pinctrl (PB12/PB13/PB15 → AF5) is applied. SCK/MOSI drop their default
  pull-downs, which would skew edges at multi-MHz MDC.
- `adc1` with `channel@5` (ADC1_IN5 = PB14).
- No `&dac3` / `&dac4` node — configured purely via LL.

---

## 8. Debugging recipe

If a capture comes back wrong, the raw bytes in `mdio_rx_buf` tell you
*where* in the chain things broke:

| Pattern | Diagnosis |
| --- | --- |
| `00 00 00 00` | DMA never advanced — SCK isn't reaching SPI2. Check the PA0 → PB13 trace, the COMP1 threshold, COMP1 enable, and that PA0 toggles on a scope. The comparator output duty is in `mdioprobe_diag_get()`. |
| `FF FF FF FF` | DMA advanced but MOSI stuck high — MDIO idle the whole NSS window. Check the PA8 → PB15 trace, the MDIO threshold, and that COMP7 isn't oscillating. |
| NSS never goes LOW (scope PA10 stuck HIGH) | No SET event. Check `comp7_out` reaches HRTIM EEV5 (EECR1: EE5 SRC=2, SNS=2) and COMP7 toggles. |
| NSS stuck LOW | No RESET event. Check TIM3 is counting (SMCR configured, CNT moving) and HRTIM EE3 SRC=2 / SNS=2, RSTF1R bit23 set. |
| NSS LOW far too wide / too narrow | Wrong `ARR`. TIM3 ARR should be 32. Measured working range is **31…38** (clocks = ARR+1): 30 and below truncates the frame, 39 and above lets a 40th clock in and a fifth byte enters the stream, collapsing the 4-byte slotting. |
| Frame shifted by N bytes | DMA byte-alignment lottery — auto-detected, logged as `DMA byte alignment auto-detected: offset=N`. If every frame decodes as plausible garbage, suspect a **stale** lock from earlier traffic and re-arm the detection with `mdioprobe_mdio_set_byte_offset(-1)`; starting a capture does this anyway. |

What you need to be able to reach while triaging, and where it lives in
`mdioprobe_api.h`:

| Capability | API |
| --- | --- |
| Run the capture loop, continuously or for N frames | `mdioprobe_capture_start()` / `_start_n()` / `_next()` / `_stop()` |
| Count frames instead of printing them — at PPU rates a per-frame log makes the console, not the chain, the bottleneck | any consumer that does not print; `mdioprobe_capture_next()` returns the frame, printing is the caller's choice |
| Raw ring, no alignment or validity checks — tells a decode failure apart from a capture failure | `mdioprobe_diag_ring_dump()` |
| Counters, locked byte offset, NSS window width, comparator duty, live threshold | `mdioprobe_diag_get()` |
| Measure MDC frequency without driving the bus | `mdioprobe_mdc_freq()` |
| Drive one Clause-22 frame to exercise the chain | `mdioprobe_c22_read()` / `mdioprobe_c22_write()` |

The comparator thresholds, the NSS window width and the stream byte
offset are applied under the hood and are intentionally not settable
through the API — they are visible in `mdioprobe_diag_get()` when a
measurement needs them.

---

## 9. Out of scope here

- The active Clause-22 master — `src/mdioprobe_mdio_master.c`.
- The target detector that supplies the bus rail — `src/mdioprobe_bus.c`.
- The public API that wraps all of this — `include/mdioprobe_api.h`.

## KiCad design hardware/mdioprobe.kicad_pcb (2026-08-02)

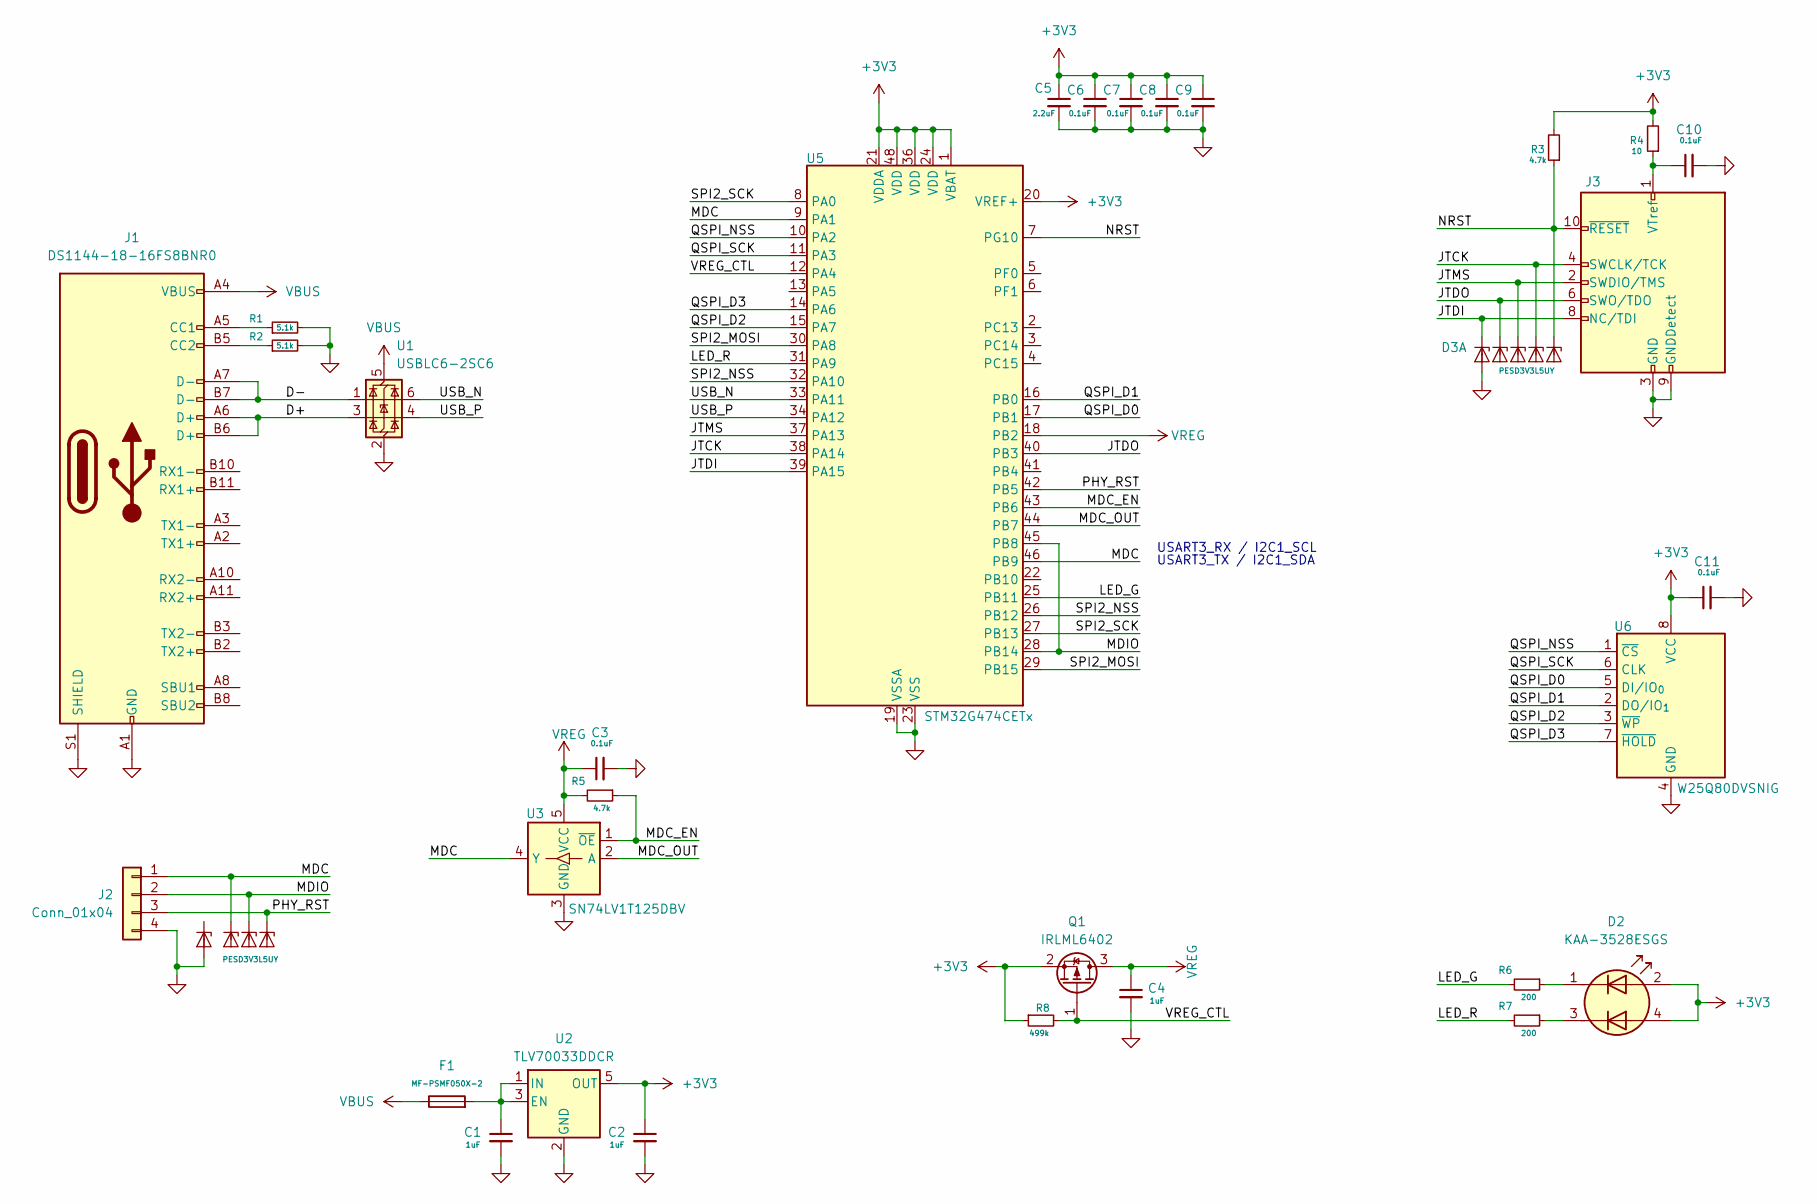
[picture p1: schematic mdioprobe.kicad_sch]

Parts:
C1, C2, C4: 1uF; C_0402_1005Metric
C3, C6, C7, C8, C9, C10, C11: 0.1uF; C_0402_1005Metric
C5: 2.2uF; C_0402_1005Metric
D1, D3: PESD3V3L5UY; SOT-363_SC-70-6
D2: KAA-3528ESGS; LED_Kingbright_AAA3528ESGCT
F1: MF-PSMF050X-2; Fuse_0805_2012Metric
J1: DS1144-18-16FS8BNR0; USB_C_Receptacle_DS1144-18
J2: Conn_01x04; PinHeader_1x04_P2.54mm_Horizontal
J3: Conn_ARM_JTAG_SWD_10; PinHeader_2x05_P1.27mm_Vertical
Q1: IRLML6402; SOT-23
R1, R2: 5.1k; R_0402_1005Metric
R3, R5: 4.7k; R_0402_1005Metric
R4: 10; R_0402_1005Metric
R6, R7: 200; R_0402_1005Metric
R8: 499k; R_0402_1005Metric
U1: USBLC6-2SC6; SOT-23-6L
U2: TLV70033DDCR; TSOT-23-5
U3: SN74LV1T125DBV; SOT-23-5
U5: STM32G474CETx; LQFP-48_7x7mm_P0.5mm
U6: W25Q80DVSNIG; SOIC-8_3.9x4.9mm_P1.27mm

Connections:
+3V3: C2.1, C5.1, C6.1, C7.1, C8.1, C9.1, C11.1, D2.2 (A1), D2.4 (A2), Q1.2 (S), R3.2, R4.2, R8.1, U2.5 (OUT), U5.1 (VBAT), U5.20 (VREF+), U5.21 (VDDA), U5.24 (VDD), U5.36 (VDD), U5.48 (VDD), U6.8 (VCC)
/D+: J1.A6 (D+), J1.B6 (D+), U1.3 (I/O2)
/D-: J1.A7 (D-), J1.B7 (D-), U1.1 (I/O1)
/JTCK: D3.5 (K4), J3.4 (SWCLK/TCK), U5.38 (PA14)
/JTDI: D3.1 (K1), J3.8 (NC/TDI), U5.39 (PA15)
/JTDO: D3.3 (K2), J3.6 (SWO/TDO), U5.40 (PB3)
/JTMS: D3.4 (K3), J3.2 (SWDIO/TMS), U5.37 (PA13)
/LED_G: R6.2, U5.25 (PB11)
/LED_R: R7.2, U5.31 (PA9)
/MDC: D1.6, J2.1, U3.4 (Y), U5.9 (PA1), U5.46 (PB9)
/MDC_EN: R5.1, U3.1 (~OE), U5.43 (PB6)
/MDC_OUT: U3.2 (A), U5.44 (PB7)
/MDIO: D1.5, J2.2, U5.28 (PB14), U5.45 (PB8)
/NRST: D3.6 (K5), J3.10 (~RESET), R3.1, U5.7 (PG10)
/PHY_RST: D1.4, J2.3, U5.42 (PB5)
/QSPI_D0: U5.17 (PB1), U6.5 (DI/IO_{0})
/QSPI_D1: U5.16 (PB0), U6.2 (DO/IO_{1})
/QSPI_D2: U5.15 (PA7), U6.3 (~WP)
/QSPI_D3: U5.14 (PA6), U6.7 (~HOLD)
/QSPI_NSS: U5.10 (PA2), U6.1 (~CS)
/QSPI_SCK: U5.11 (PA3), U6.6 (CLK)
/SPI2_MOSI: U5.29 (PB15), U5.30 (PA8)
/SPI2_NSS: U5.26 (PB12), U5.32 (PA10)
/SPI2_SCK: U5.8 (PA0), U5.27 (PB13)
/USB_N: U1.6 (I/O1), U5.33 (PA11)
/USB_P: U1.4 (I/O2), U5.34 (PA12)
/VREG_CTL: Q1.1 (G), R8.2, U5.12 (PA4)
GND: C1.2, C2.2, C3.2, C4.2, C5.2, C6.2, C7.2, C8.2, C9.2, C10.2, C11.2, D1.2, D3.2 (A), J1.A1 (GND), J1.A12 (GND), J1.B1 (GND), J1.B12 (GND), J1.S1 (SHIELD), J2.4, J3.3 (GND), J3.5 (GND), J3.9 (GNDDetect), R1.2, R2.2, U1.2 (GND), U2.2 (GND), U3.3 (GND), U5.19 (VSSA), U5.23 (VSS), U5.35 (VSS), U5.47 (VSS), U6.4 (GND)
unnamed: D2.1 (K1), R6.1
unnamed: D2.3 (K2), R7.1
unnamed: J1.A5 (CC1), R1.1
unnamed: J1.B5 (CC2), R2.1
unnamed: C10.1, J3.1 (VTref), R4.1
unnamed: C1.1, F1.2, U2.1 (IN), U2.3 (EN)
VBUS: F1.1, J1.A4 (VBUS), J1.A9 (VBUS), J1.B4 (VBUS), J1.B9 (VBUS), U1.5 (VBUS)
VREG: C3.1, C4.1, Q1.3 (D), R5.2, U3.5 (VCC), U5.18 (PB2)

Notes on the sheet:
USART3_RX / I2C1_SCL
USART3_TX / I2C1_SDA

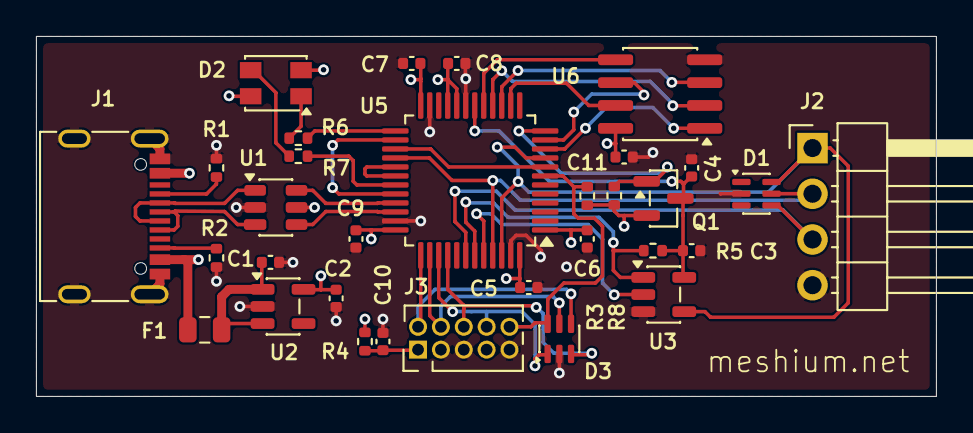
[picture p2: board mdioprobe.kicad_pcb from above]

Board: 4 copper layers, 50.0 x 20.0 mm, 32 parts (0 on the bottom side), 36 nets.

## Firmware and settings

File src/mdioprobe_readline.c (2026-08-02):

/*
 * Copyright (c) 2026 Meshium
 *               Aleksandr Senin <al@meshium.net>
 *
 * SPDX-License-Identifier: Apache-2.0
 *
 * A line reader for the CLI, so Tab can complete commands.
 *
 * MicroPython's readline is good — arrow keys, Home/End, history — and none
 * of it is reimplemented here. The one thing it does not offer is a way in:
 * Tab is wired straight to `mp_repl_autocomplete()`, which completes Python
 * names out of the `__main__` globals and the qstr pool. At a `mdio>` prompt
 * that is useless, and there is no hook, callback or config option to point
 * it elsewhere — the call in readline.c is by name.
 *
 * So the loop that `readline()` runs (shared/readline/readline.c) is
 * repeated here with one branch added: Tab is taken out before
 * readline_process_char() can see it, handed to a Python completer, and the
 * text to insert is fed back in character by character. Feeding it back is
 * what keeps this small — the redraw, the cursor and the history stay
 * upstream's job, and this file never touches a terminal escape except to
 * move the cursor to end of line.
 *
 * Why not the `mp_hal_readline` macro, which would have made input() do all
 * this: mp_builtin_input() prints the prompt itself and passes readline an
 * empty one (py/modbuiltins.c:224-230), so a completer reached that way
 * could never redraw the prompt after listing candidates. Being its own
 * function also leaves input() alone for user scripts.
 */

#include <string.h>

#include <zephyr/kernel.h>

#include "py/mphal.h"
#include "py/obj.h"
#include "py/runtime.h"
#include "shared/readline/readline.h"

/* Set from Python: fn(line) -> (insert, listing_or_None). */
static mp_obj_t completer = MP_OBJ_NULL;

void mdioprobe_readline_set_completer(mp_obj_t fn)
{
	completer = (fn == mp_const_none) ? MP_OBJ_NULL : fn;
}

static void feed(const char *text, size_t len)
{
	for (size_t i = 0; i < len; i++) {
		readline_process_char((int)(unsigned char)text[i]);
	}
}

/*
 * Complete at the cursor.
 *
 * The cursor is forced to end of line first, with an End escape fed through
 * the state machine. Two reasons: the completer only ever sees the whole
 * line, so completing from the middle would insert in the wrong place; and
 * the line vstr belongs to us, which means its contents are readable here
 * while the cursor position is private to readline. Moving the cursor is the
 * cheaper of the two ways to make those agree. `ESC [ F` is handled
 * unconditionally by readline, unlike the Ctrl-E alias, which is behind
 * MICROPY_REPL_EMACS_KEYS and off in this build.
 */
static void complete(vstr_t *line, const char *prompt)
{
	if (completer == MP_OBJ_NULL) {
		return;
	}

	feed("\x1b[F", 3);

	mp_obj_t arg = mp_obj_new_str(vstr_str(line), vstr_len(line));
	mp_obj_t result;

	/* A broken completer must not take the command line down with it. */
	nlr_buf_t nlr;
	if (nlr_push(&nlr) != 0) {
		nlr_pop();
		return;
	}
	result = mp_call_function_1(completer, arg);
	nlr_pop();

	mp_obj_t *parts;
	size_t n_parts;

	mp_obj_get_array(result, &n_parts, &parts);
	if (n_parts != 2) {
		return;
	}

	/* Candidates, if the completer had more than one. Printed above a fresh
	 * prompt, which then has to be redrawn along with what was typed —
	 * readline only ever draws what changes. */
	if (parts[1] != mp_const_none) {
		size_t len;
		const char *text = mp_obj_str_get_data(parts[1], &len);

		mp_hal_stdout_tx_str("\r\n");
		mp_hal_stdout_tx_strn(text, len);
		mp_hal_stdout_tx_str("\r\n");
		mp_hal_stdout_tx_str(prompt);
		mp_hal_stdout_tx_strn(vstr_str(line), vstr_len(line));
	}

	size_t insert_len;
	const char *insert = mp_obj_str_get_data(parts[0], &insert_len);

	feed(insert, insert_len);
}

/*
 * Read one line. Returns 0, or the control character that ended it, exactly
 * like readline() — the caller turns those into the same exceptions input()
 * raises.
 */
int mdioprobe_readline(vstr_t *line, const char *prompt)
{
	/* readline_init() prints the prompt itself (readline.c:558) — printing
	 * it here as well is how this drew two of them. */
	readline_init(line, prompt);

	for (;;) {
		int c = mp_hal_stdin_rx_chr();

		if (c == '\t') {
			complete(line, prompt);
			continue;
		}

		int r = readline_process_char(c);

		if (r >= 0) {
			return r;
		}
	}
}

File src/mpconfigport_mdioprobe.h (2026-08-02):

/*
 * Copyright (c) 2026 Meshium
 *               Aleksandr Senin <al@meshium.net>
 *
 * SPDX-License-Identifier: Apache-2.0
 *
 * MicroPython configuration for the MDIO probe.
 *
 * Starts from the upstream Zephyr port's configuration and then takes things
 * away. Two different reasons to remove something, worth keeping apart:
 *
 *   - size. The image also carries the capture chain, the vreg loop and USB,
 *     and the GC heap is a static array competing for the same 128 KB.
 *
 *   - safety. `machine.Pin`, `machine.SPI` and friends would hand a script
 *     direct control of pins this firmware is actively using: PB6/PB7/PB8
 *     belong to the bitbang master, PB12-PB15 to the SPI capture slave,
 *     PA0/PA8/PA10 carry comparator outputs into it. A script that reassigns
 *     one of those does not fail loudly — it silently breaks capture. The
 *     probe's own API is the only sanctioned way to touch the hardware, so
 *     the generic peripheral modules are removed rather than left as a trap.
 */

#include "ports/zephyr/mpconfigport.h"

/* VFS stays on. It is what gives `import` and `open()` over the FAT volume,
 * and it is also the condition under which the port runs `_boot.py` at all
 * (see MICROPY_VFS && MICROPY_MODULE_FROZEN_MPY in ports/zephyr/main.c). */

/* The CLI reads its command line with input(), which is not in the ROM
 * feature level the port defaults to. It routes through the same readline
 * the REPL uses, so enabling it also buys cursor movement, history and
 * Ctrl-C handling — which is why there is no hand-rolled line editor here. */
#undef MICROPY_PY_BUILTINS_INPUT
#define MICROPY_PY_BUILTINS_INPUT   (1)

/* Line history. Upstream defaults to 8, which is short for a session spent
 * stepping through registers. The cost is 4 bytes per slot in BSS (the array
 * is a GC root in mp_state_ctx) plus the lines themselves on the GC heap, in
 * 16-byte blocks — so 24 slots of typical commands is well under a kilobyte
 * of a 32 KB heap.
 *
 * Note the history slots are *not* cleared on a soft reset on this port:
 * ports/zephyr/main.c never calls readline_init0(), unlike every other port,
 * so the pointers would survive into a re-initialised heap. _boot.py calls
 * mdioprobe.history_reset() to close that. */
#undef MICROPY_READLINE_HISTORY_SIZE
#define MICROPY_READLINE_HISTORY_SIZE (24)

/* --- safety: no generic peripheral access from Python --- */
#undef MICROPY_PY_MACHINE
#define MICROPY_PY_MACHINE          (0)
#undef MICROPY_PY_MACHINE_I2C
#define MICROPY_PY_MACHINE_I2C      (0)
#undef MICROPY_PY_MACHINE_I2C_TARGET
#define MICROPY_PY_MACHINE_I2C_TARGET (0)
#undef MICROPY_PY_MACHINE_SOFTI2C
#define MICROPY_PY_MACHINE_SOFTI2C  (0)
#undef MICROPY_PY_MACHINE_SPI
#define MICROPY_PY_MACHINE_SPI      (0)
#undef MICROPY_PY_MACHINE_SOFTSPI
#define MICROPY_PY_MACHINE_SOFTSPI  (0)
#undef MICROPY_PY_MACHINE_UART
#define MICROPY_PY_MACHINE_UART     (0)
#undef MICROPY_PY_MACHINE_WDT
#define MICROPY_PY_MACHINE_WDT      (0)
#undef MICROPY_PY_MACHINE_PWM
#define MICROPY_PY_MACHINE_PWM      (0)
#undef MICROPY_PY_MACHINE_ADC
#define MICROPY_PY_MACHINE_ADC      (0)

/* --- size: nothing on this board uses these --- */
#undef MICROPY_PY_SOCKET
#define MICROPY_PY_SOCKET           (0)
#undef MICROPY_PY_BLUETOOTH
#define MICROPY_PY_BLUETOOTH        (0)
#undef MICROPY_PY_ZSENSOR
#define MICROPY_PY_ZSENSOR          (0)

/* The `zephyr` module stays: zephyr.FileSystem is how the FAT volume gets
 * mounted into the VFS. */

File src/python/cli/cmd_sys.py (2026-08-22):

"""help, exit, version, and running commands from a file."""

import mdioprobe

from cli.parser import ranged
from cli.registry import CommandError, by_category, command, lookup, ordered_categories

# A running command cannot be interrupted on this firmware: the console path
# never scans input for the interrupt character, so Ctrl-C is only read
# between commands. That makes the ceiling load-bearing rather than tidy — a
# mistyped `sleep 600000` would be ten minutes with a power cycle as the only
# way out. Same reasoning as `monitor`'s default duration.
SLEEP_MAX_MS = 60000


def _print_detail(ctx, text):
    """Print a help text one line at a time.

    Deliberately not `text.strip().split("\\n")`. Detail strings live in
    flash as part of the frozen module; strip() copies the whole thing onto
    the heap and split() then builds a list of every line on top of that. On
    a 32 KB GC heap the longest of them (`mv`, ~2 KB) failed outright with
    MemoryError. Walking the string and slicing one line at a time keeps the
    largest allocation down to a single line.
    """
    start = 0
    end = len(text)

    while start < end and text[start] == "\n":
        start += 1
    while end > start and text[end - 1] == "\n":
        end -= 1

    while start < end:
        cut = text.find("\n", start, end)
        if cut < 0:
            cut = end
        ctx.out.line("{}", text[start:cut])
        start = cut + 1


@command("help", category="system", syntax="help [command]",
         summary="list commands, or explain one")
def cmd_help(ctx, args):
    if args:
        cmd = lookup(args[0])
        ctx.out.line("{}", cmd.syntax)
        if cmd.summary:
            ctx.out.line("  {}", cmd.summary)
        if cmd.detail:
            ctx.out.line("")
            _print_detail(ctx, cmd.detail)
        return

    groups = by_category()
    for category in ordered_categories(groups):
        ctx.out.line("")
        ctx.out.line("{}:", category)
        for cmd in groups[category]:
            ctx.out.line("  {:<10} {}", cmd.name, cmd.summary)


@command("exit", category="system", syntax="exit",
         summary="leave the shell for the Python REPL")
def cmd_exit(ctx, args):
    ctx.shell.running = False
    ctx.out.line("dropping to the REPL; `import cli.shell; cli.shell.run()` returns")


@command("exec", category="system", syntax="exec <file>",
         summary="run commands from a file, stopping at the first failure",
         detail="Blank lines and lines starting with # are skipped.")
def cmd_exec(ctx, args):
    if len(args) != 1:
        raise CommandError("usage: exec <file>")

    try:
        source = open(args[0])
    except OSError:
        raise CommandError("cannot open {}".format(args[0]))

    with source:
        for number, line in enumerate(source, 1):
            line = line.strip()
            if not line or line.startswith("#"):
                continue
            ctx.out.line("+ {}", line)
            if not ctx.shell.run_line(line):
                raise CommandError("stopped at line {} of {}".format(number, args[0]))


@command("sleep", category="system", syntax="sleep <ms>",
         summary="wait, for a script that needs a step to settle",
         detail="""
Milliseconds, matching `rst` and `mdc`, and at most 60000.

A pause is a command rather than something `exec` understands so that the
line means the same thing typed at the prompt as it does in a file — `exec`
has no syntax of its own beyond blank lines and `#`, and it is worth keeping
that way.

The ceiling is not tidiness. A running command cannot be interrupted on this
firmware: the console path never scans input for the interrupt character, so
Ctrl-C is only read between commands. A mistyped `sleep 600000` would be ten
minutes with a power cycle as the only way out.

For anything that needs a loop or a condition rather than a fixed wait, use
`script <file>`, where `time.sleep_ms()` is available along with the rest of
Python.
""")
def cmd_sleep(ctx, args):
    import time

    if len(args) != 1:
        raise CommandError("usage: sleep <ms>")

    time.sleep_ms(ranged(args[0], 0, SLEEP_MAX_MS, "sleep"))


@command("use", category="system", syntax="use [module | drop [module]]",
         summary="load a command module from the volume",
         detail="""
Chip-specific commands are not built into the firmware. They live as Python
files on the volume — `/flash/lib/mv6321.py` and the like — and `use` brings
one in:

    use mv6321
    mv6321 id 6

Without an argument it lists what is loaded and what each module gave.
Running it again on the same name reloads the file, taking that module's
previous commands away first, so editing a helper and re-loading it does
what you expect.

    use drop <module>   take one back
    use drop            take them all back

There is a limit on how many can be loaded at once: MicroPython compiles
each one on the device, and that needs a large contiguous block of a heap
only 48 KB in the first place. Two of the Marvell helpers fit together and a
third fails; `use drop` is the answer, and you are normally in front of one
chip anyway — though dropping does not always give the memory back in one
piece, and then a soft reset does. Cross-compiled `.mpy` helpers skip the
compile, so all three fit and each loads in a fifth of the time; what they do
not do is take less room once loaded.

An error while loading prints the traceback rather than a tidied message:
this is your own code, and the traceback is the useful answer. Commands the
module managed to register before it failed are taken back.
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

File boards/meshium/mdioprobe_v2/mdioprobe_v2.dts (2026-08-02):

/*
 * Copyright (c) 2026 Meshium
 *               Aleksandr Senin <al@meshium.net>
 *
 * SPDX-License-Identifier: Apache-2.0
 *
 * MDIO Probe v2 — STM32G474CET6 (LQFP48), custom carrier board.
 *
 * Capture path pin assignment is identical to the mdioprobe_g474 bring-up
 * board; what were jumper wires there are PCB traces here:
 *
 *   PA0 (COMP1_OUT, MDC digital)  --trace--> PB13 (SPI2_SCK)
 *   PA8 (COMP7_OUT, MDIO digital) --trace--> PB15 (SPI2_MOSI)
 *   PA10 (HRTIM1_CHB1, NSS latch) --trace--> PB12 (SPI2_NSS)
 *
 * Everything on the capture chain (COMP1/COMP7, DAC3/DAC4 thresholds,
 * TIM3 one-pulse counter, HRTIM SR-latch, SPI2 slave + DMA1) is set up
 * from LL code, not from DT — see docs/CAPTURE.md.
 */

/dts-v1/;
#include <st/g4/stm32g474Xe.dtsi>
#include <st/g4/stm32g474c(b-c-e)tx-pinctrl.dtsi>
#include <zephyr/dt-bindings/gpio/gpio.h>
#include <zephyr/dt-bindings/adc/adc.h>
#include <zephyr/dt-bindings/i2c/i2c.h>

/ {
	model = "Meshium MDIO Probe v2";
	compatible = "meshium,mdioprobe-v2";

	chosen {
		zephyr,sram = &sram0;
		zephyr,flash = &flash0;
		/*
		 * No VCP on this board: the console is a USB CDC ACM port.
		 * Declared here rather than by the `cdc-acm-console` snippet,
		 * because the firmware builds its own USB device — it has to
		 * be able to tear CDC down and come back as mass storage, and
		 * the snippet only ever registers CDC.
		 */
		zephyr,console = &cdc_acm_console;
	};

	/*
	 * Colours verified on hardware 2026-07-22: the initial pinout notes
	 * had them the other way round (PA9=R, PB11=G) — the board actually
	 * wires PA9 to green and PB11 to red.
	 */
	leds: leds {
		compatible = "gpio-leds";

		green_led: led_g {
			gpios = <&gpioa 9 GPIO_ACTIVE_LOW>;
			label = "LED_G";
		};

		red_led: led_r {
			gpios = <&gpiob 11 GPIO_ACTIVE_LOW>;
			label = "LED_R";
		};
	};

	aliases {
		led0 = &green_led;
		led1 = &red_led;
		watchdog0 = &iwdg;
		die-temp0 = &die_temp;
		volt-sensor0 = &vref;
		volt-sensor1 = &vbat;
	};

	/*
	 * Bitbang Clause-22 master (the "generate" half of the probe).
	 *
	 * MDC leaves the board through an external tri-state buffer:
	 *   MDC_EN  (PB6, active LOW) enables the buffer output;
	 *   MDC_OUT (PB7) is the bitbang clock fed into the buffer input.
	 * The buffer is powered from the programmable translator supply
	 * (see mdioprobe_vreg.c) so MDC swings at the target's logic level.
	 * Its output also loops back to PA1/COMP1, so the sniffer's clock
	 * front end sees the probe's own MDC.
	 *
	 * MDIO is split: PB8 drives the line (open-drain, no pull, parked
	 * as Analog while receiving so it cannot load the bus), while the
	 * read-back path is the *sniffer* front end — PB14 → COMP7, whose
	 * digital output the master samples. Reading through the comparator
	 * means the master works at whatever logic level the target uses,
	 * with the same DAC threshold the capture path was calibrated to.
	 */
	mdio_master: mdio_master {
		compatible = "mdioprobe,mdio-master";
		status = "okay";
		mdc-gpios = <&gpiob 7 GPIO_ACTIVE_HIGH>;
		/*
		 * Open-drain: a 4.7 kΩ pull-up to VREG (the buffer's supply)
		 * makes the inactive level. Driving it push-pull would
		 * back-power the VREG rail from the 3.3 V domain.
		 */
		mdc-en-gpios = <&gpiob 6 (GPIO_ACTIVE_LOW | GPIO_OPEN_DRAIN)>;
		mdio-out-gpios = <&gpiob 8 (GPIO_ACTIVE_HIGH | GPIO_OPEN_DRAIN)>;
	};

	mdioprobe_config {
		compatible = "mdioprobe,config";
		/*
		 * MDIO idle-voltage sense. PB14 is shared three ways:
		 * ADC1_IN5 (this channel), COMP7_INP (sniffer) and the
		 * bitbang master's read-back. All three are read-only —
		 * the pin stays Analog at all times.
		 */
		io-channels = <&adc1 5>;
		io-channel-names = "mdio_adc";
		/*
		 * PHY_RST on the target connector: open-drain, no pull —
		 * the line must be pulled up by the target's own supply.
		 */
		target-reset-gpios = <&gpiob 5 (GPIO_ACTIVE_LOW | GPIO_OPEN_DRAIN)>;
	};

};

&clk_hsi {
	status = "okay";
};

/*
 * No crystal on the board: HSI16 feeds the PLL for the 170 MHz core
 * clock, and the USB FS peripheral runs off HSI48.
 *
 * HSI48 free-running is only ~±3 % over temperature, which is outside
 * the ±0.25 % USB FS requires. `src/mdioprobe_usb.c` enables the CRS
 * peripheral to auto-trim HSI48 against USB SOF packets — Zephyr's G4
 * clock driver does not do this for us.
 */
&clk_hsi48 {
	status = "okay";
};

&pll {
	div-m = <4>;
	mul-n = <85>;
	div-p = <2>;
	div-q = <2>;
	div-r = <2>;
	clocks = <&clk_hsi>;
	status = "okay";
};

&rcc {
	clocks = <&pll>;
	clock-frequency = <DT_FREQ_M(170)>;
	ahb-prescaler = <1>;
	apb1-prescaler = <1>;
	apb2-prescaler = <1>;
};

zephyr_udc0: &usb {
	cdc_acm_console: cdc_acm_console {
		compatible = "zephyr,cdc-acm-uart";
	};

	pinctrl-0 = <&usb_dm_pa11 &usb_dp_pa12>;
	pinctrl-names = "default";
	status = "okay";
};

/*
 * Drop the default internal pull-down from SPI2 SCK/MOSI. The bus is
 * push-pull driven on-die by COMP1_OUT (PA0) and COMP7_OUT (PA8) through
 * short PCB traces; a ~40 kΩ pull-down would skew rising edges at
 * multi-MHz MDC. NSS keeps its pull-up — the HRTIM latch (POL1=1) rests
 * it inactive HIGH between frames.
 */
&pinctrl {
	spi2_sck_pb13_nopull: spi2_sck_pb13_nopull {
		pinmux = <STM32_PINMUX('B', 13, AF5)>;
		slew-rate = "very-high-speed";
	};

	spi2_mosi_pb15_nopull: spi2_mosi_pb15_nopull {
		pinmux = <STM32_PINMUX('B', 15, AF5)>;
		slew-rate = "very-high-speed";
	};
};

/*
 * SPI2 slave = the capture engine. The Zephyr driver is enabled only so
 * its init applies this pinctrl group (PB12/PB13/PB15 → AF5); the API is
 * never called. src/mdioprobe_mdio_api.c programs SPI2 + DMA1_Channel1 +
 * DMAMUX1 directly. Note PB14 is deliberately NOT listed — on this board
 * it is the analog MDIO sense pin, not SPI2_MISO.
 */
&spi2 {
	pinctrl-0 = <&spi2_sck_pb13_nopull &spi2_mosi_pb15_nopull &spi2_nss_pb12>;
	pinctrl-names = "default";
	status = "okay";
};

&adc1 {
	pinctrl-0 = <&adc1_in5_pb14>;
	pinctrl-names = "default";
	/* AHB/4 = 42.5 MHz, comfortably under the 60 MHz ADC ceiling. */
	st,adc-clock-source = "SYNC";
	st,adc-prescaler = <4>;
	status = "okay";
	#address-cells = <1>;
	#size-cells = <0>;

	/* PB14 = ADC1_IN5 — MDIO idle level (also COMP7_INP@INPSEL=0). */
	channel@5 {
		reg = <5>;
		zephyr,gain = "ADC_GAIN_1";
		zephyr,reference = "ADC_REF_INTERNAL";
		zephyr,acquisition-time = <ADC_ACQ_TIME_DEFAULT>;
		zephyr,resolution = <12>;
	};
};

/*
 * ADC2_IN12 (PB2, translator Vout sense) and DAC1_CH1 (PA4, MOSFET gate)
 * are driven from LL inside src/mdioprobe_vreg.c — the 10 kHz control
 * loop needs direct register access, so no Zephyr ADC/DAC node here.
 * DAC3_CH1 / DAC4_CH1 (comparator thresholds) are internal-only on G4:
 * no pin, no pinctrl, configured from src/mdioprobe_adc_dac.c.
 */
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

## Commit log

2026-08-02 mdioprobe v2 — pre-release
    An MDIO probe on a custom STM32G474CET6 board. It watches a Clause-22 bus
    without touching it, and it can drive one.
    Capture is done in hardware and the CPU only decodes finished frames. The
    analogue MDIO and MDC lines go through comparators with a DAC threshold; TIM3
    counts 32 MDC edges from the start bit and an HRTIM latch turns that into
    chip-select for SPI2 in slave mode, so nothing is reconfigured per frame and a
    busy bus cannot outrun the firmware. Verified against a real external master:
    284350 consecutive frames from an 88E6321 PPU at 6.25 MHz MDC with no decode
    errors, no ring overruns and no DMA faults.
    The master is bit-banged Clause 22 timed off the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
    [mdioprobe-B_Cu.gbr, mdioprobe-B_Mask.gbr, mdioprobe-B_Paste.gbr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]
2026-08-04 Verify mv6240 against an 88E6240 and correct it
    First run against silicon: 88E6240 rev 1, multi-chip address 18.
    VERIFIED = True.
    * PARTS gains 0x240, read off the part. No document here prints it.
    * SERDES address 0x0F confirmed: it answers with model 0x2a. It had been
    an inference.
    * SERDES register 22 reads 0x0000 after a software reset, so the page
    write in _probe_fiber is required, not defensive.
    * Global1 0x00 bits 15:12 read 0b1100 and survive a reset. Bit 15 does
    not read a constant zero, as the helper claimed.
    * Global1 0x04 bit 14 reads one, 0x4001. reset writes the register back
    as read.
    probe writes nothing, as intended: PHYDetect identical before and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
2026-08-16 Add `sleep` for scripts, and make a failed read fail the command
    `sleep <ms>` pauses inside `exec`, capped at 60 s because a running command
    cannot be interrupted.
    A register dump still prints every register when one of them will not answer,
    but the command now ends in error, so `exec` stops instead of running on
    through a dead bus.
    [cmd_mdio.py, cmd_sys.py]
2026-08-22 Clause-22 read alignment, and port operations for the Marvell helpers
    - master: skip one turnaround clock unconditionally instead of hunting for
    the acknowledgement zero; the acknowledgement is now a presence check only
    - add `ta [strict|relaxed]` and the `c22_probe()` two-samples-per-clock
    diagnostic
    - add `cli/mvport.py`: the port registers the three Link Street families
    encode identically, and the operations built on them
    - mv6321, mv6240, mv6390: `port <sw> <ports> up|down|auto`, `state <s>` and
    `rgmii none|rx|tx|both`; an explicit port list is required for all three
    - `up|down|auto` picks what to power from the port's C_Mode: internal PHY,
    external PHY, SERDES, both on SGMII,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
    [cmd_mdio.py, cmd_sys.py, complete.py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]
